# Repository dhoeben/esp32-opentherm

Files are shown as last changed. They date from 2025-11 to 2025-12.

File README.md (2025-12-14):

# OpenTherm Gateway 
 

This project implements a fully native OpenTherm Gateway using an ESP32-S3 chip and ESPHome. 
It acts as a modern, reliable, and flexible interface between your boiler and Home Assistant — featuring full OpenTherm communication, diagnostics, and web-accessible emergency controls.
It is designed to work with the PCB attached in the .pcb folder, to create the PCB just download the gerber files and order at your convenience.

Feel free to also checkout my [battery powered thermostat](https://github.com/dhoeben/esp32-thermostat), which features an e-ink display, fully customizable and has it's own PCB you can just order! 

### ⚠️ Use case
The PCB is not designed to connect to a thermostat via wire! It is a stand-alone gateway which gets all data from Home Assistant. Most boilers do have a 12-24v output, which you can connect your wired thermostat to for power. But the data from the thermostat **must** be available in Home Assistant.

*This is a hobby project, use at your own risk. It might damage your boiler when used incorrectly.*
*Do not sell!*

### 🛒 Shopping list
| Item | Name | Quantity | Price | Link |
| :--- | :---: | :--- | :--- | :--- |
| **Screws** | M3 10-12mm | 4 | $0.50 - $5 | Any |
| **PCB** | Attached in .pcb folder | 1 | $50 - $200 | [Link](.pcb/gerber_files.zip) |
| **Case** | Attached in .pcb folder | 1 | $10 - $80 | [Link](.pcb/) |

### ⬇️ Installation
1) Order PCB using gerber_files and 3D print / assemble case.
2) Download latest release
3) Update secrets.yaml
4) Use vscode or flash tool to create firmware 
5) Flash to PCB using USB.
6) Connect to boiler's OpenTherm connectors.
7) Connect to Home Assistant

### ⚙️ PCB Overview
- 4 layer PCB build from scratch
- Used the best part and foodprint for the task.
- Created Galvanic isolation, so no false signals or inteferance.
- Low power usage and "light off principle"
- 7 multicolor LED's for status of the gateway
- Used an overpowered ESP32-S3, so there will be no issues in the future
- Used BME680 on PCB for a back-up temperature. Also gives CO2 equivalent, for monitoring of air quality in boiler room. 
**Warning: Air quality sensing is just for fun, always use proper safety equipment for air quality monitoring.**

This also works with *any* ESP32-S3, however it is not fully supported and tested. Make sure to update secrets.yaml according to your config.

### 🚀 Featuress
- Full OpenTherm Protocol Support
- Integrated Home Assistant Support
- Emergency Mode (Offline Control)
- Optional weather Compensation (Equitherm or boilers own)  
- Diagnostic & Monitoring (boiler state, flame, fault codes) 

### 🖥️ Web Interface
- Access via http://otgateway.local (or the device IP)
- Option to toggle Emergency Mode and enable offline control
- Option to control even without Home Assistant or during (temporary) failure.
- Heating (CH) control
- Domestic Hot Water (DHW) control
- All controls are processed locally on the ESP chip — not on Home Assistant. 
### 🧮 Equitherm Heating Curve
This project implements a custom **Equithermic control algorithm** that dynamically adjusts the **boiler flow temperature** based on outdoor and indoor conditions.  
It uses the same principle as weather-compensated control, but allows you to fully tune the curve parameters via Home Assistant. 
This takes time, but eventually will save you a lot of money (and it is envoirmental friendly).

You can also switch it off.

<details>
<summary><strong>More information</strong></summary>

```T_flow = n * (T_set + k - T_out) + t + (T_set - T_in) * fb```

| Symbol | Definition | Source |
|:-------|:------------|:-------|
| **T₍flow₎** | Calculated target flow temperature (°C) | Sent to boiler via OpenTherm (DID 0x11) |
| **T₍out₎** | Outdoor temperature (°C) | From Home Assistant weather sensor |
| **T₍in₎** | Current indoor temperature (°C) | From indoor temperature sensor |
| **T₍set₎** | Desired indoor setpoint (°C) | From ESPHome `climate` target |
| **n** | Curve exponent / slope multiplier | Tunable number (default ≈ 1.2–1.3) |
| **k** | Base slope factor | Tunable number (default ≈ 0.8–1.0) |
| **t** | Curve offset (°C) | Shifts the curve up/down; usually near indoor target |
| **fb** | Feedback gain | Correction factor based on indoor deviation |
| **max_ch_temp** | Maximum boiler flow limit (°C) | Adjustable from Home Assistant |

The Equithermic control curve automatically increases boiler flow temperature when it’s colder outside, keeping the indoor temperature stable with minimal cycling and optimal condensing efficiency.

- **n** and **k** shape how steeply the flow temperature reacts to outdoor changes.  
- **t** vertically shifts the entire curve, roughly aligning it with the desired comfort level.  
- **fb** applies an indoor feedback correction:  
  - If the indoor temperature is *below* the target, the flow temperature increases slightly.  
  - If it’s *above* the target, it decreases slightly.  
- The final calculated temperature is **clamped** to the `Maximum CH Temperature` number you define in Home Assistant.

</details>

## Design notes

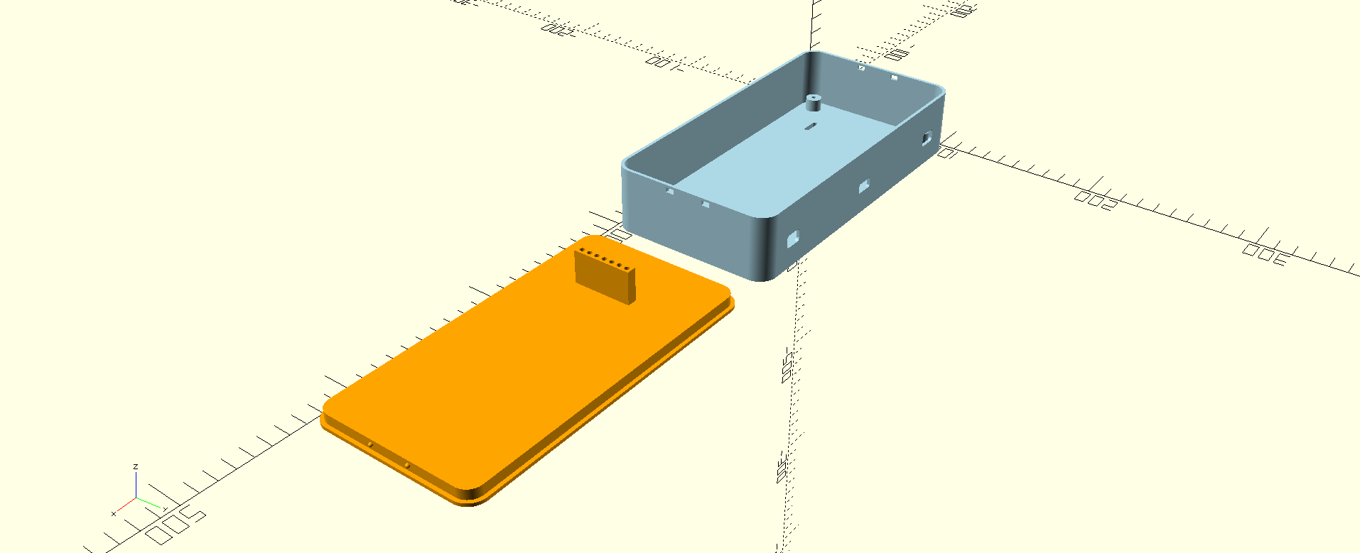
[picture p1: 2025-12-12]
.pcb/case_3d.png

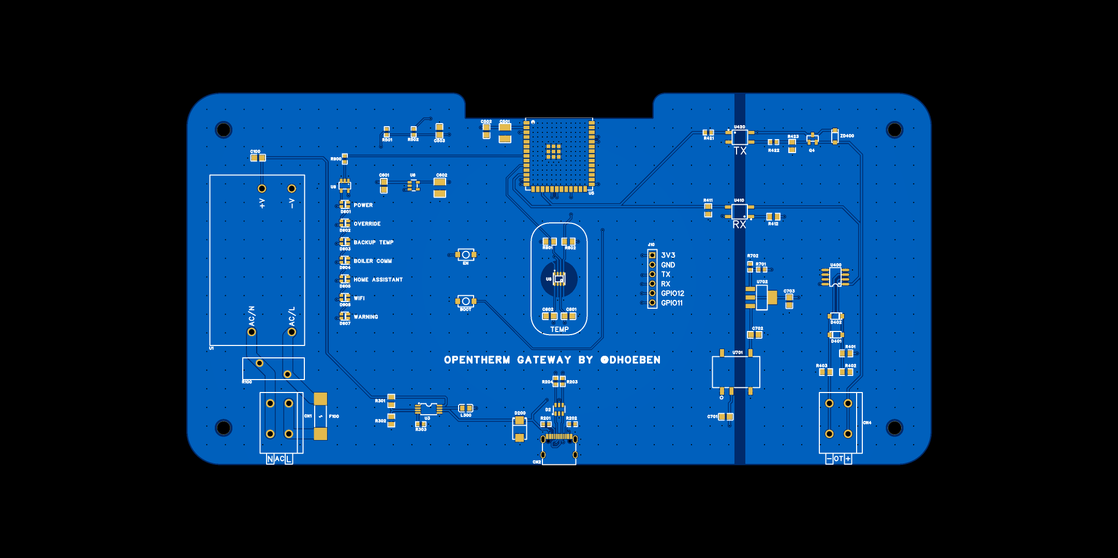
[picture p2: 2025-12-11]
.pcb/pcb_2d.png

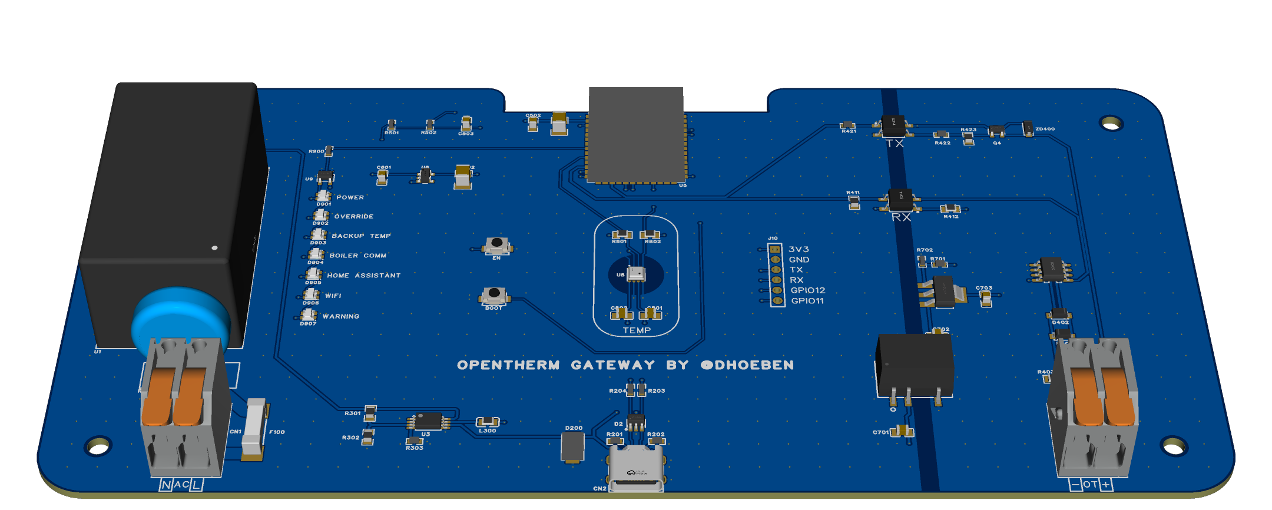
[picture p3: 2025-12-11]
.pcb/pcb_3d.png

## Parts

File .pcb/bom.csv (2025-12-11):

No. | Quantity | Comment | Designator | Footprint | Value | Manufacturer Part | Manufacturer | Supplier Part | Supplier
1 | 1 | 22uF | C100 | C0805 | 22uF | CC0805MKX5R8BB226 | YAGEO(国巨) | C784585 | LCSC
2 | 2 | 22uF | C501,C602 | C1210 | 22uF | CC1210KKX7R8BB226 | YAGEO(国巨) | C5341638 | LCSC
3 | 2 | 100nF | C502,C503 | C0805 | 100nF | CC0805KRX7R7BB104 | YAGEO(国巨) | C519980 | LCSC
4 | 1 | 1uF | C601 | C0805 | 1uF | CC0805KKX7R9BB105 | YAGEO(国巨) | C91185 | LCSC
5 | 2 | 4.7uF | C701,C703 | C0805 | 4.7uF | CC0805KKX7R8BB475 | YAGEO(国巨) | C354262 | LCSC
6 | 1 | 470nF | C702 | C0805 | 470nF | CC0805KKX7R9BB474 | YAGEO(国巨) | C106843 | LCSC
7 | 2 | 100nF | C801,C802 | C0805 | 100nF | GRM21BR71H104KA01L | muRata(村田) | C77082 | LCSC
8 | 2 | 2604-1102 | CN1,CN4 | CONN-TH_2604-1102 |  | 2604-1102 | WAGO(万可) | C3309286 | LCSC
9 | 1 | TYPE-C-31-M-12 | CN2 | USB-C_SMD-TYPE-C-31-M-12_1 |  | TYPE-C-31-M-12 | 韩国韩荣 | C165948 | LCSC
10 | 1 | USBLC6-2SC6 | D2 | SOT-23-6_L2.9-W1.6-P0.95-LS2.8-BL |  | USBLC6-2SC6 | ST(意法半导体) | C7519 | LCSC
11 | 1 | SMBJ5.0A | D200 | SMB_L4.6-W3.6-LS5.3-RD |  | SMBJ5.0A | Littelfuse(美国力特) | C83333 | LCSC
12 | 2 | 1N4148W-E3-08 | D401,D402 | SOD-123_L2.8-W1.8-LS3.7-RD |  | 1N4148W-E3-08 | VISHAY(威世) | C241939 | LCSC
13 | 7 | WS2812C-2020-V1 | D901,D902,D903,D904,D905,D906,D907 | LED-SMD_4P-L2.0-W2.0-TL_WS2812B-2020 |  | WS2812C-2020-V1 | worldsemi | C2976072 | LCSC
14 | 1 | 04611.25ER | F100 | FUSE-SMD_L10.1-W3.1 |  | 04611.25ER | Littelfuse(美国力特) | C99554 | LCSC
15 | 1 | B25420220-6PB0513-H85C32 | J10 | HDR-TH_B25420220-6PB0513-H85C32 |  | B25420220-6PB0513-H85C32 | HMTCONN(华明通) | C42385696 | LCSC
16 | 1 | BLM21PG121SN1D | L300 | L0805 |  | BLM21PG121SN1D | muRata(村田) | C79382 | LCSC
17 | 1 | BC817-40-QR | Q4 | SOT-23-3_L2.9-W1.3-P1.90-LS2.4-BR |  | BC817-40-QR | Nexperia(安世) | C5205149 | LCSC
18 | 1 | 420pF@1kHz | R100 | RES-TH_L16.5-W5.9-P7.50-D0.8-S3.00 | 420pF@1kHz | 14D471K | RUILON(瑞隆源) | C8852 | LCSC
19 | 2 | 5.1kΩ | R201,R202 | R0603 | 5.1kΩ | 0603WAF5101T5E | UNI-ROYAL(厚声) | C23186 | LCSC
20 | 2 | 0Ω | R203,R204 | R0603 | 0Ω | 0603WAF0000T5E | UNI-ROYAL(厚声) | C21189 | LCSC
21 | 1 | 20kΩ | R301 | R0805 | 20kΩ | 0805W8F2002T5E | UNI-ROYAL(厚声) | C4328 | LCSC
22 | 3 | 10kΩ | R302,R411,R423 | R0805 | 10kΩ | 0805W8F1002T5E | UNI-ROYAL(厚声) | C17414 | LCSC
23 | 4 | 470Ω | R303,R421,R501,R900 | R0603 | 470Ω | 0603WAF4700T5E | UNI-ROYAL(厚声) | C23179 | LCSC
24 | 1 | 47kΩ | R401 | R0805 | 47kΩ | 0805W8F4702T5E | UNI-ROYAL(厚声) | C17713 | LCSC
25 | 1 | 330Ω | R402 | R0805 | 330Ω | 0805W8F3300T5E | UNI-ROYAL(厚声) | C17630 | LCSC
26 | 1 | 10Ω | R403 | R0805_NEW | 10Ω | 0805W8F100JT5E | UNI-ROYAL(厚声) | C17415 | LCSC
27 | 1 | 3.3kΩ | R412 | R0805 | 3.3kΩ | 0805W8F3301T5E | UNI-ROYAL(厚声) | C26010 | LCSC
28 | 1 | 1kΩ | R422 | R0603 | 1kΩ | 0603WAF1001T5E | UNI-ROYAL(厚声) | C21190 | LCSC
29 | 1 | 10kΩ | R502 | R0603 | 10kΩ | 0603WAD1002T5E | UNI-ROYAL(厚声) | C167144 | LCSC
30 | 1 | 240Ω | R701 | R0603 | 240Ω | 0603WAD2400T5E | UNI-ROYAL(厚声) | C423057 | LCSC
31 | 1 | 3kΩ | R702 | R0603 | 3kΩ | 0603WAF3001T5E | UNI-ROYAL(厚声) | C4211 | LCSC
32 | 2 | 4.7kΩ | R801,R802 | R0805 | 4.7kΩ | 0805W8F4701T5E | UNI-ROYAL(厚声) | C17673 | LCSC
33 | 2 | TS-1088R-02026 | SW501,SW502 | SW-SMD_L3.9-W3.0-P4.45 |  | TS-1088R-02026 | XUNPU(讯普) | C455280 | LCSC
34 | 1 | IRM-05-5 | U1 | PWRM-TH_IRM-05-5 |  | IRM-05-5 | null | C48603696 | LCSC
35 | 1 | TPS2113APW | U3 | TSSOP-8_L4.4-W3.0-P0.65-LS6.4-TL |  | TPS2113APW | TI(德州仪器) | C2861975 | LCSC
36 | 1 | ESP32-S3-WROOM-1-N16R8 | U5 | WIRELM-SMD_ESP32-S3-WROOM-1 |  | ESP32-S3-WROOM-1-N16R8 | ESPRESSIF(乐鑫) | C2913202 | LCSC
37 | 1 | TLV75733PDBVR | U6 | SOT-23-5_L2.9-W1.6-P0.95-LS2.8-BL |  | TLV75733PDBVR | TI(德州仪器) | C485517 | LCSC
38 | 1 | BME680 | U8 | LGA-8_L3.0-W3.0-P0.80-TR |  | BME680 | Bosch(博世) | C125972 | LCSC
39 | 1 | SN74AHCT1G125DBVR | U9 | SOT-23-5_L3.0-W1.7-P0.95-LS2.8-BR |  | SN74AHCT1G125DBVR | TI(德州仪器) | C7484 | LCSC
40 | 1 | LM393DR | U400 | SOIC-8_L5.0-W4.0-P1.27-LS6.0-BL |  | LM393DR | TI(德州仪器) | C67470 | LCSC
41 | 2 | LTV-357T | U410,U420 | SOP-4_L3.9-W4.4-P2.54-LS7.0-TL |  | LTV-357T | LITEON(光宝) | C119089 | LCSC
42 | 1 | B0524XT-1WR3 | U701 | SMD-8_5P-L12.7-W8.3-P2.54-LS11.2-BL_B0524XT-1WR3 |  | B0524XT-1WR3 | EVISUN(易成) | C22388257 | LCSC
43 | 1 | LM317DCYR | U702 | SOT-223-3_L6.5-W3.4-P2.30-LS7.0-BR |  | LM317DCYR | TI(德州仪器) | C51466 | LCSC
44 | 1 | BZT52C12 | ZD400 | SOD-123_L2.7-W1.8-LS3.7-RD-A |  | BZT52C12 | YTL(亚特联) | C52145100 | LCSC

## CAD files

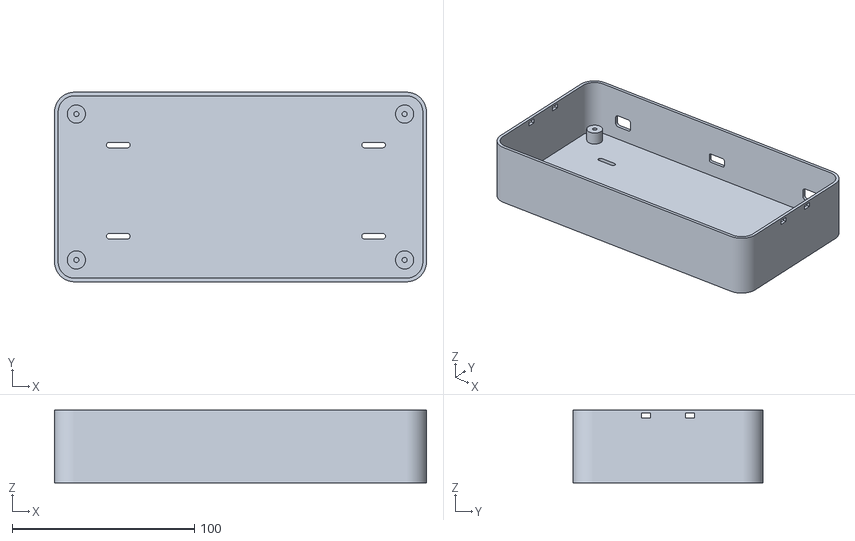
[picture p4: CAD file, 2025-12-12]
.pcb/housing.stl
204.0 x 104.0 x 40.0

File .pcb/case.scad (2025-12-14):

$fn = 256;

// ==========================================
// CONFIGURATION
// ==========================================

RENDER_PART = "both"; 

// ==========================================
// PARAMETERS
// ==========================================

// THICKNESS SETTINGS
T = 2.0;                // Now 2mm for strength
BOTTOM_T = 4.0;         

// VERTICAL FIXTURES
ORIGINAL_REQ_STANDOFF = 10; 
FIXED_PCB_Z = T + ORIGINAL_REQ_STANDOFF; 

// PCB DIMENSIONS
PCB_W = 100.0;
PCB_L = 200.0;
PCB_T = 1.6;
PCB_CORNER_R = 9.0;     // Exact radius of the PCB corners

// HOUSING DIMENSIONS
H = 40.0;               
SCREW_HOLE_R = 1.4;     
PCB_HOLE_OFFSET = 10.0; 

// SNAP FIT PARAMETERS
SNAP_Y_LOCS = [40, PCB_W + (2*T) - 40]; 
SNAP_Z_POS = H - 3.0;                   
SNAP_RADIUS = 1.3;                      // Slightly larger for better click
HOLE_WIDTH = 5.0;                       
HOLE_HEIGHT = 3.0;                      

// USB PORT PARAMETERS
USB_WIDTH = 12;         
USB_HEIGHT = 6;         

// WAGO CONNECTOR PARAMETERS
WAGO_WIDTH = 12;
WAGO_HEIGHT = 8;
wago_x_positions = [25, 175]; 

// LID & LED PARAMETERS
LID_T = 2.0;            
LIP_H = 6.0;            // Deeper lip for T=2mm stability
TOLERANCE = 0.25;       // Slightly more tolerance for thicker walls
BAFFLE_W = 6.0;         
BAFFLE_H = (H - FIXED_PCB_Z - PCB_T - TOLERANCE); 

// LED CONFIGURATION
LED_COUNT = 7;
LED_PITCH = 5.0;        
LED_HOLE_R = 1.5;       
LED_X_ON_PCB = 42.5;    
LED_Y_START_USER = -30.0; 

// ==========================================
// DERIVED VALUES
// ==========================================

W = (PCB_W + (2 * T));    
L = (PCB_L + (2 * T));
// Outer Radius = PCB Radius + Wall Thickness
OUTER_R = PCB_CORNER_R + T; 

PCB_ORIGIN_X_SCAD = T;
PCB_ORIGIN_Y_SCAD = T + PCB_W;

// ==========================================
// HELPER MODULES
// ==========================================

module rounded_rect_2d_tl(w, h, r) {
    translate([r, r]) offset(r=r) square([w - 2*r, h - 2*r], center=false);
}

module outer_block(w, h, t, r) {
    linear_extrude(height=t) rounded_rect_2d_tl(w, h, r);
}

module capsule_hole(length, width) {
    r = width / 2;
    hull() {
        translate([0, 0]) circle(r = r);
        translate([length, 0]) circle(r = r);
    }
}

// ==========================================
// MAIN HOUSING MODULE
// ==========================================

module housing() {
    x_min = T + PCB_HOLE_OFFSET;
    x_max = T + PCB_L - PCB_HOLE_OFFSET;
    y_min = T + PCB_HOLE_OFFSET;
    y_max = T + PCB_W - PCB_HOLE_OFFSET;
    
    post_positions = [[x_min, y_min], [x_max, y_min], [x_max, y_max], [x_min, y_max]];
    slot_positions = [[30, 75], [30, 25], [170, 75], [170, 25]];

    difference() {
        // BASE BLOCK (Uses Calculated OUTER_R)
        outer_block(L, W, H, OUTER_R);
        
        // INTERIOR CUTOUT (Uses exact PCB_CORNER_R)
        translate([T, T, BOTTOM_T])
            linear_extrude(height = H - BOTTOM_T + 0.05)
                rounded_rect_2d_tl(PCB_L, PCB_W, PCB_CORNER_R);
        
        // WALL MOUNT SLOTS
        for (pos = slot_positions) {
            translate([pos.x, pos.y, -1])
                linear_extrude(height = BOTTOM_T + 2) capsule_hole(10, 3);
        }

        // WAGO CUTOUTS
        for (x_pos = wago_x_positions) {
            translate([x_pos + T, W - (T/2), FIXED_PCB_Z + (WAGO_HEIGHT/2) + 1]) 
                rotate([90, 0, 0]) 
                    linear_extrude(height = T + 10, center=true)
                        hull() {
                            w_half = WAGO_WIDTH/2 - 2; h_half = WAGO_HEIGHT/2 - 2;
                            translate([-w_half, -h_half]) circle(r=2);
                            translate([ w_half, -h_half]) circle(r=2);
                            translate([ w_half,  h_half]) circle(r=2);
                            translate([-w_half,  h_half]) circle(r=2);
                        }
        }
        
        // USB CUTOUT
        translate([
            T + (PCB_L / 2), 
            W - (T / 2), 
            FIXED_PCB_Z + PCB_T + (USB_HEIGHT / 2) 
        ])
            rotate([90, 0, 0]) 
                linear_extrude(height = T + 10, center=true)
                    hull() {
                        w_half = USB_WIDTH/2 - 1; 
                        h_half = USB_HEIGHT/2 - 1;
                        translate([-w_half, -h_half]) circle(r=1);
                        translate([ w_half, -h_half]) circle(r=1);
                        translate([ w_half,  h_half]) circle(r=1);
                        translate([-w_half,  h_half]) circle(r=1);
                    }
                    
        // SNAP HOLES
        for (y_pos = SNAP_Y_LOCS) {
            translate([-1, y_pos - (HOLE_WIDTH/2), SNAP_Z_POS - (HOLE_HEIGHT/2)])
                cube([T + 2, HOLE_WIDTH, HOLE_HEIGHT]);
            
            translate([L - T - 1, y_pos - (HOLE_WIDTH/2), SNAP_Z_POS - (HOLE_HEIGHT/2)])
                cube([T + 2, HOLE_WIDTH, HOLE_HEIGHT]);
        }
    }

    // STANDOFFS
    for (pos = post_positions) {
        translate([pos.x, pos.y, 0])
            difference() {
                cylinder(h = FIXED_PCB_Z, r = 5);
                translate([0, 0, -1]) cylinder(h = FIXED_PCB_Z + 2, r = SCREW_HOLE_R);
            }
    }
}

// ==========================================
// LID MODULE
// ==========================================

module lid() {
    y_start_scad = PCB_ORIGIN_Y_SCAD + LED_Y_START_USER;
    led_array_len = (LED_COUNT - 1) * LED_PITCH;
    baffle_total_len = led_array_len + 6; 
    baffle_center_y = y_start_scad - (led_array_len / 2);

    difference() {
        union() {
            // LID PLATE
            linear_extrude(height = LID_T) rounded_rect_2d_tl(L, W, OUTER_R);
            
            // LID LIP (Matches PCB Radius minus tolerance)
            translate([T + TOLERANCE, T + TOLERANCE, -LIP_H])
                linear_extrude(height = LIP_H)
                     rounded_rect_2d_tl(
                        L - 2*T - 2*TOLERANCE, 
                        W - 2*T - 2*TOLERANCE, 
                        PCB_CORNER_R - TOLERANCE
                     );
                    
            // LIGHT BAFFLE
            translate([
                PCB_ORIGIN_X_SCAD + LED_X_ON_PCB - (BAFFLE_W/2), 
                baffle_center_y - (baffle_total_len / 2), 
                -BAFFLE_H
            ])
                cube([BAFFLE_W, baffle_total_len, BAFFLE_H]);
                
            // SNAP BUMPS
            snap_z_local = -(H - SNAP_Z_POS);
            
            for (y_pos = SNAP_Y_LOCS) {
                translate([T + TOLERANCE, y_pos, snap_z_local])
                    rotate([0, 90, 0]) sphere(r=SNAP_RADIUS);
                            
                translate([L - T - TOLERANCE, y_pos, snap_z_local])
                    rotate([0, 90, 0]) sphere(r=SNAP_RADIUS);
            }
        }

        // LED HOLES
        for (i = [0 : LED_COUNT - 1]) {
            posX = PCB_ORIGIN_X_SCAD + LED_X_ON_PCB;
            posY = PCB_ORIGIN_Y_SCAD + LED_Y_START_USER - (i * LED_PITCH);
            translate([posX, posY, -BAFFLE_H - 1]) 
                cylinder(h = LID_T + BAFFLE_H + 2, r = LED_HOLE_R);
        }
    }
}

// ==========================================
// RENDER LOGIC
// ==========================================

if (RENDER_PART == "box" || RENDER_PART == "both") {
    color("LightBlue") housing();
}

if (RENDER_PART == "lid" || RENDER_PART == "both") {
    translate([L + 20, W, 0]) 
        rotate([180, 0, 0]) 
            translate([0, 0, -LID_T]) 
                color("Orange") lid();
}

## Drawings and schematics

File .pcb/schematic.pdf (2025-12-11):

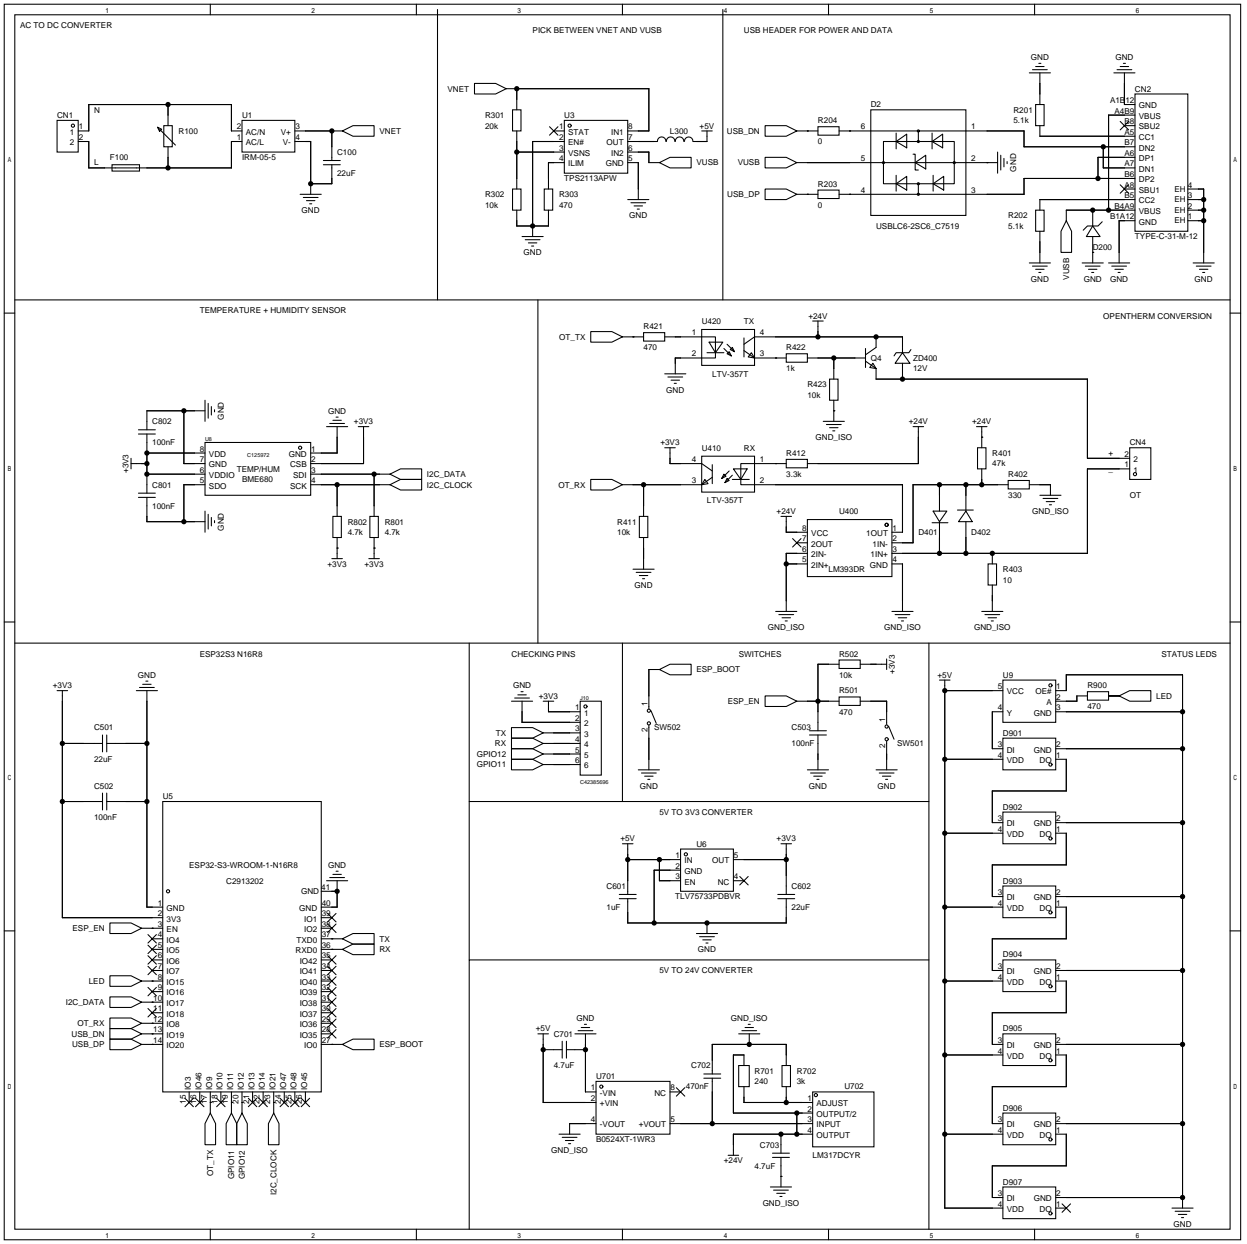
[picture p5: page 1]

AC TO DC CONVERTER

PICK BETWEEN VNET AND VUSB

USB HEADER FOR POWER AND DATA

OPENTHERM CONVERSION TEMPERATURE + HUMIDITY SENSOR

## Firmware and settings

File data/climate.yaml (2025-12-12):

climate:
  # Central Heating
  - platform: thermostat
    name: "Central Heating"
    icon: mdi:thermostat
    id: ch_climate
    sensor: adaptive_indoor_temp
    humidity_sensor: ha_indoor_humidity
    device_id: ch
    web_server:
      sorting_group_id: sorting_control

    visual:
      min_temperature: 5
      max_temperature: 40
      temperature_step: 0.5

    min_heating_off_time: 30s
    min_heating_run_time: 30s
    min_idle_time: 30s

    preset:
      - name: away
        default_target_temperature_low: 12
      - name: eco
        default_target_temperature_low: 12
      - name: comfort
        default_target_temperature_low: 12
      - name: boost
        default_target_temperature_low: 12

    default_preset: eco

    target_temperature_change_action:
      - lambda: |-
          float new_temp = id(ch_climate).target_temperature;

          auto preset_opt = id(ch_climate).preset;
          auto preset = preset_opt.value_or(esphome::climate::CLIMATE_PRESET_NONE);

          if (preset != esphome::climate::CLIMATE_PRESET_AWAY) {
            id(climate_last_set_temp) = new_temp;
            id(climate_last_active_temp) = new_temp; 
          }

    preset_change:
      - lambda: |-
          auto preset_opt = id(ch_climate).preset;
          auto preset = preset_opt.value_or(esphome::climate::CLIMATE_PRESET_NONE);

          float set_temp;

          if (preset == esphome::climate::CLIMATE_PRESET_AWAY) {
            set_temp = id(preset_away_temp).state;
          } else {
            set_temp = id(climate_last_active_temp);
          }

          auto call = id(ch_climate).make_call();
          call.set_target_temperature(set_temp);
          call.perform();

    heat_action:
      - lambda: |-
          auto ot = opentherm::OpenThermComponent::get_singleton();
          if (ot == nullptr) return;

          std::string mode = id(compensation_mode).current_option();
          std::string preset = "eco";
          if (id(ch_climate).preset.has_value())
            preset = to_string(id(ch_climate).preset.value());

          float flow_target = 0.0f;

          // BOOST → max flow
          if (preset == "boost") {
            flow_target = id(max_boiler_temp_heating).state;
            ESP_LOGI("climate", "BOOST → MAX flow %.1f°C", flow_target);

          // ECO / COMFORT → equitherm
          } else if (mode == "Equitherm") {
            // Nieuwe aanroep: via het equitherm_ object
            flow_target = ot->equitherm_.calculate_target(ot->boiler_.get_limit_temp());
            ESP_LOGI("climate", 
                     "Equitherm (%s) → Flow=%.1f°C",
                     preset.c_str(), flow_target);

          // Boiler curve fallback
          } else {
            ESP_LOGI("climate", "Boiler internal curve active");
            return;
          }

          // Clamp to max allowed flow
          float max_flow = id(max_boiler_temp_heating).state;
          if (flow_target < 10.0f) flow_target = 10.0f;
          if (flow_target > max_flow) flow_target = max_flow;

          uint16_t raw = (uint16_t)(flow_target * 256.0f);

          ot->send_request(opentherm::OT_MSG_WRITE_DATA, 0x11, raw);

          ESP_LOGI("climate",
                   "Heating ON | Preset=%s | Flow=%.1f°C",
                   preset.c_str(), flow_target);

    idle_action:
      - lambda: |-
          auto ot = opentherm::OpenThermComponent::get_singleton();
          if (ot == nullptr) return;

          std::string preset = "eco";
          if (id(ch_climate).preset.has_value())
            preset = to_string(id(ch_climate).preset.value());

          // Default idle → cold pipes
          float flow_target = 5.0f;

          // Comfort / Boost warm idle
          if (preset == "comfort" || preset == "boost") {
            flow_target = 15.0f;
          }

          uint16_t raw = (uint16_t)(flow_target * 256.0f);

          // AANGEPAST: Nieuwe send methode
          ot->send_request(opentherm::OT_MSG_WRITE_DATA, 0x11, raw);

          ESP_LOGI("climate",
                   "Heating OFF | Preset=%s | Idle Flow=%.1f°C",
                   preset.c_str(), flow_target);

  # Domestic Hot Water
  - platform: thermostat
    name: "Domestic Hot Water"
    id: dhw_climate
    device_id: dhw
    sensor: dhw_temp
    icon: mdi:water-boiler
    web_server:
      sorting_group_id: sorting_control

    visual:
      min_temperature: 40
      max_temperature: 65
      temperature_step: 1.0

    min_heating_off_time: 30s
    min_heating_run_time: 30s
    min_idle_time: 30s

    preset:
      - name: comfort
        default_target_temperature_low: 60
      - name: eco
        default_target_temperature_low: 60

    default_preset: eco

    heat_action:
      - lambda: |-
          auto ot = opentherm::OpenThermComponent::get_singleton();
          if (ot == nullptr) return;
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

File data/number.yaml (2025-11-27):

number:
  # Equitherm
  - platform: template
    name: "Equitherm N (Slope)"
    id: eq_n
    min_value: 0.1
    max_value: 1.5
    step: 0.01
    mode: box 
    entity_category: config
    restore_value: true
    optimistic: true
    unit_of_measurement: ""
    icon: mdi:alpha-n
    web_server:
      sorting_group_id: sorting_equitherm

  - platform: template
    name: "Equitherm K (Offset)"
    id: eq_k
    min_value: 0.0
    max_value: 10.0
    step: 0.01
    mode: box 
    entity_category: config
    restore_value: true
    optimistic: true
    unit_of_measurement: ""
    icon: mdi:alpha-k
    web_server:
      sorting_group_id: sorting_equitherm

  - platform: template
    name: "Equitherm T (Base)"
    id: eq_t
    min_value: -20.0
    max_value: 20.0
    step: 0.01
    mode: box 
    entity_category: config
    restore_value: true
    optimistic: true
    device_class: temperature
    icon: mdi:alpha-t
    web_server:
      sorting_group_id: sorting_equitherm

  - platform: template
    name: "Equitherm Feedback Gain"
    id: eq_fb_gain
    min_value: -10.0
    max_value: 10.0
    step: 0.01
    mode: box 
    entity_category: config
    restore_value: true
    optimistic: true
    unit_of_measurement: ""
    icon: mdi:alpha-f
    web_server:
      sorting_group_id: sorting_equitherm


  # Max values
  - platform: template
    name: "CH Maximum Temperature"
    id: max_boiler_temp_heating
    min_value: 30
    max_value: 90
    mode: box 
    step: 1
    device_class: temperature
    restore_value: true
    optimistic: true
    icon: mdi:thermometer-high
    web_server:
      sorting_group_id: sorting_ch

  - platform: template
    name: "DHW Maximum Temperature"
    id: max_boiler_temp_water
    min_value: 30
    max_value: 90
    mode: box 
    step: 1
    device_class: temperature
    restore_value: true
    optimistic: true
    icon: mdi:thermometer-high
    web_server:
      sorting_group_id: sorting_dhw

  # Climate entity
  - platform: template
    name: "Preset away temperature"
    id: preset_away_temp
    device_id: ch
    icon: mdi:home-export-outline
    min_value: 5
    max_value: 20
    mode: box 
    entity_category: config
    step: 0.5
    initial_value: 12
    device_class: temperature
    restore_value: true
    optimistic: true
    web_server:
      sorting_group_id: sorting_ch


# Temperature compensation
  - platform: template
    id: indoor_temp_offset
    name: "Temperature Offset"
    icon: mdi:tune-variant
    entity_category: config
    device_id: ch
    device_class: temperature_delta
    restore_value: true
    mode: box  
    min_value: -5.0
    max_value: 5.0
    step: 0.1
    optimistic: true
    initial_value: 0.0
    disabled_by_default: true
    web_server:
      sorting_group_id: sorting_ch

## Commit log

2025-10-16 Add flow sensor
2025-10-16 Created comfort switch
2025-10-16 Add restart button
2025-10-16 Added limits for temperature
2025-10-17 Changed board to esp32s3
2025-10-17 Add option to switch between Equitherm and boiler compensation logic
2025-10-17 Switched to packages
2025-10-17 Improved sensor naming
2025-10-17 Added preset .. to sensors
2025-10-18 Removed outdoor sensor because its replaced with weather entity
2025-10-18 Water heater is now a climate entity
2025-10-18 Board issues
2025-10-18 Fixes for board to work
2025-10-18 Improved entities for Home Assistant device overview
2025-10-18 Add device_class
2025-10-19 Split up into three devices for better overview in HA
2025-10-20 Moved sensors to template for commonality
2025-10-21 Include onboard LED for status
2025-10-26 Add backup hardware sensor
2025-10-26 Add backup temp to status LED
2025-10-26 Moved all sensors to sensors.h/.cpp for future-proof
2025-10-27 Change sensor name
2025-11-10 Added PCB info
    [BOM.csv]
2025-11-11 Added PCB files
    [BOM.csv]
2025-11-20 Update files to work with PCB
2025-11-20 Updated to new pins and refining
    [BOM.csv]
2025-11-20 Update Wifi status and LED test
2025-11-20 Add temperature offset input
2025-11-20 Switched between BME680 library
2025-11-21 Changed LED's to more distinct colors
    [BOM.csv, bill_of_materials.csv]
2025-11-27 Added more wifi sensors
2025-11-27 Only switch temp when away
2025-12-11 Update according to PCB
2025-12-11 Update PCB
    [bill_of_materials.csv, bom.csv]
2025-12-12 Updated 3D models for the case
    [case.scad, housing.stl]
2025-12-12 Update light sequence iaw PCB
